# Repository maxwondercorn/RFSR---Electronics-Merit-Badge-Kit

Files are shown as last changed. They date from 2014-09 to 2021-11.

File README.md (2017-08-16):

Electronics Merit Badge Kit
==================================

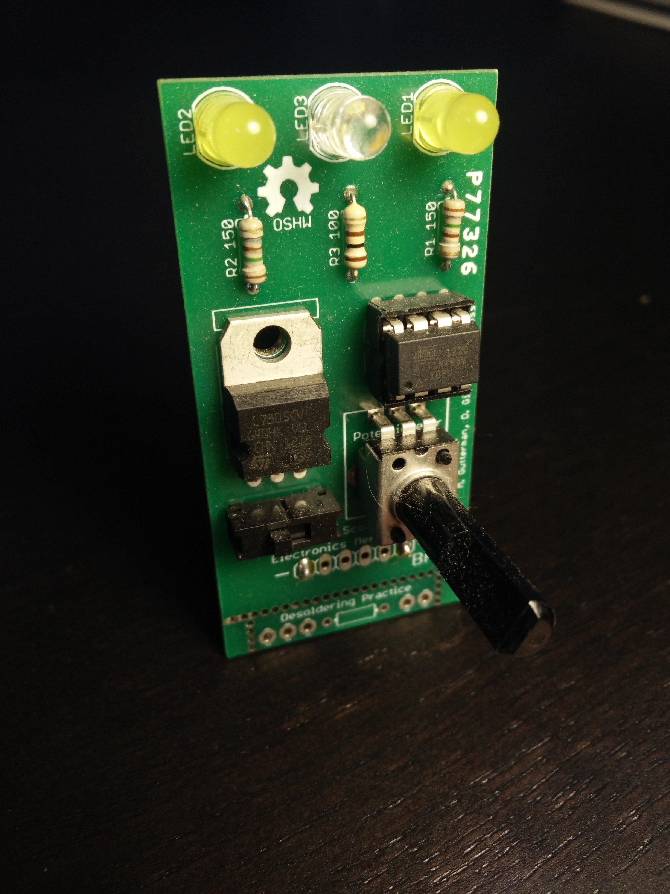
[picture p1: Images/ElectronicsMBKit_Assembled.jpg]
Electronics MB Kit Assembled


Small ATtiny (Arduino IDE Compatible) microcontroller based kit used to teach Electronics Merit Badge at Resica Falls Scout Reservation.  Once assembled and functional, the kit allows selection of various LED display modes (Flickering Candle, Nightlight, Flashlight, Etc.) by rotating the on-board potentiometer.  Kit design is intended to meet all relevant badge requirements and expose scouts to a variety of component types at the lowest cost possible.

Repository Contents
-------------------

* **/Hardware** - Eagle Schematic / PCB Layouts & Bill Of Materials
    - PCB silkscreen periodically updated to match summer camp staff members currently teaching Electronics Merit Badge at Resica Falls Scout Reservation.
    - Bill Of Materials includes vendors / part numbers from the last production run.
* **/Software** - Demo Arduino sketch for the kit.  Code is intended to be easy to understand for beginners.
* **/Images** - Images of the kit, both assembled and in parts.

Firmware Programming
-------------------

As of the 2017 summer camp season, kit firmware is programmed using the following tools:

#### Hardware
An [Arduino Uno](https://store.arduino.cc/usa/arduino-uno-rev3) and an [AVR Programmer Shield](http://www.electrodragon.com/w/AVR_Programmer_Arduino_Shield) with ZIF socket.

Image of programming rig: [/Images/ElectronicsMBProgrammingRig.jpg](https://raw.githubusercontent.com/crossfireprod/RFSR---Electronics-Merit-Badge-Kit/master/Images/ElectronicsMBProgrammingRig.jpg)

#### Software
The Arduino Uno is used as an in system programmer (ISP) through use of the [ArduinoISP](https://github.com/arduino/ArduinoISP) sketch packaged with [Arduino 1.8.3](https://www.arduino.cc/en/main/software) to program the ATtiny 45/85 targets.  ATtiny core files available from [David Mellis' GitHub Repository](https://github.com/damellis/attiny), using [full instructions published by high-low tech](http://highlowtech.org/?p=1695) allow the ATtiny AVR microcontrollers used in the kits to be programmed directly from the Arduino IDE.

License
-------------------

All contents of this repository are released under [Creative Commons Share-alike 4.0](http://creativecommons.org/licenses/by-sa/4.0/).



Kit Design By: [*ZachCross.com*](https://ZachCross.com)

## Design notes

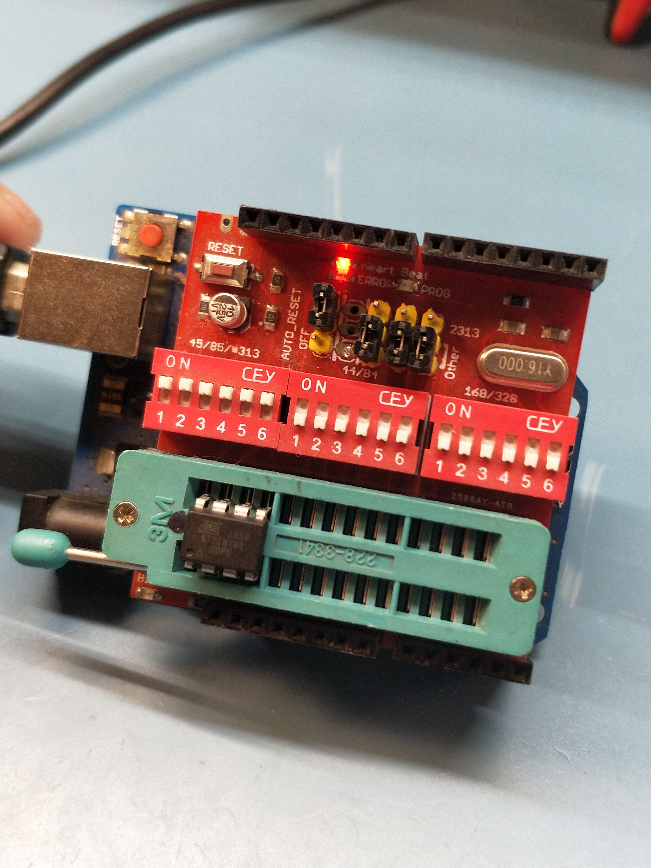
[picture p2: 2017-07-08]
Images/ElectronicsMBProgrammingRig.jpg

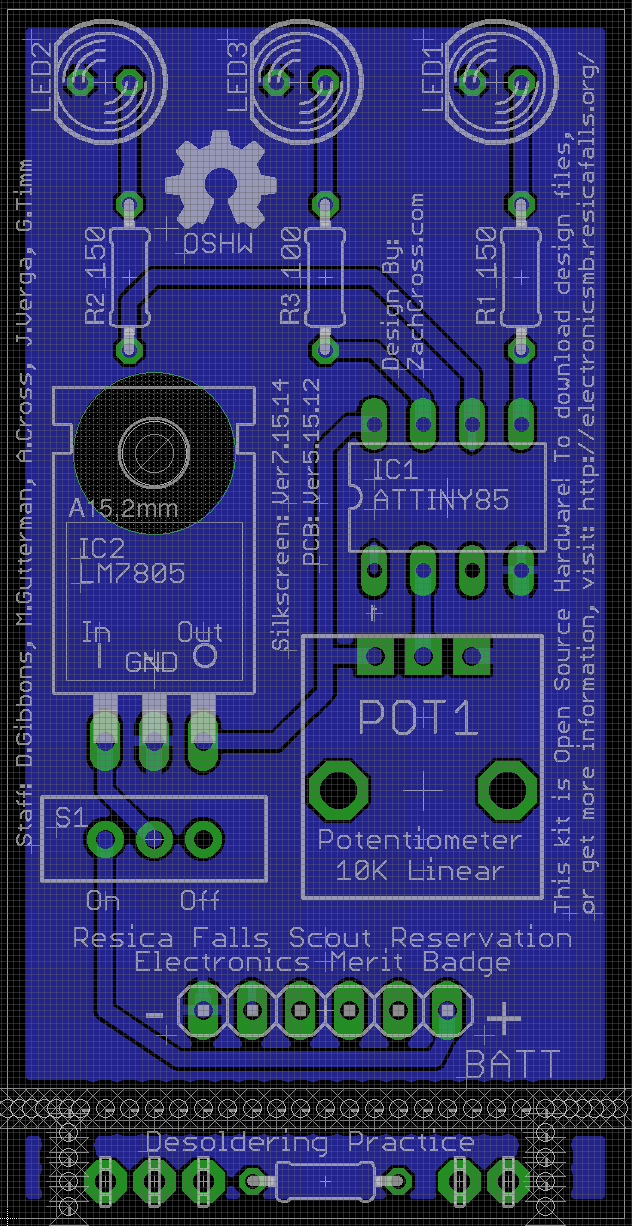
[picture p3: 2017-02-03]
Images/ElectronicsMBKit_PCBLayout.png

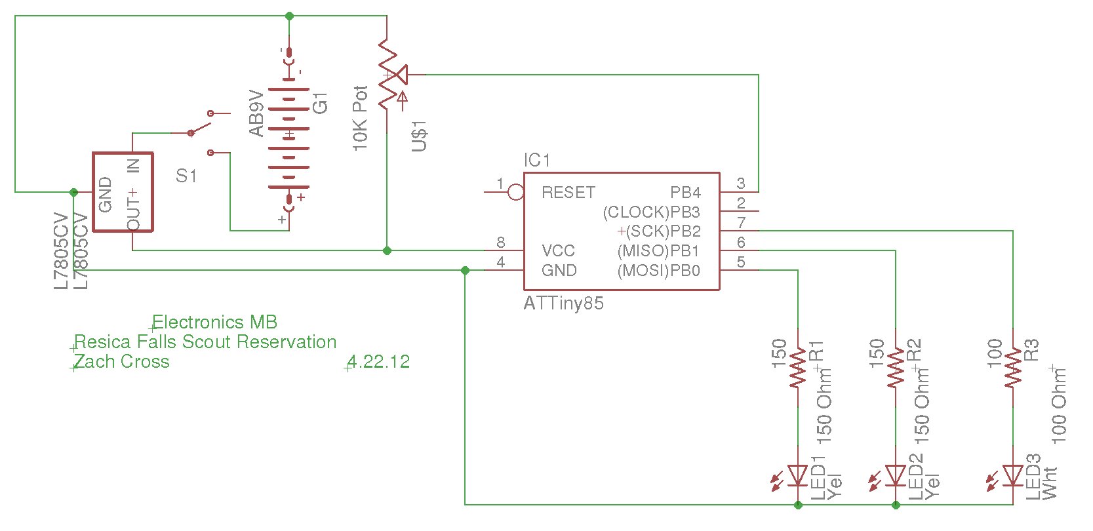
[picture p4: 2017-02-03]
Images/ElectronicsMBKit_Schematic.png

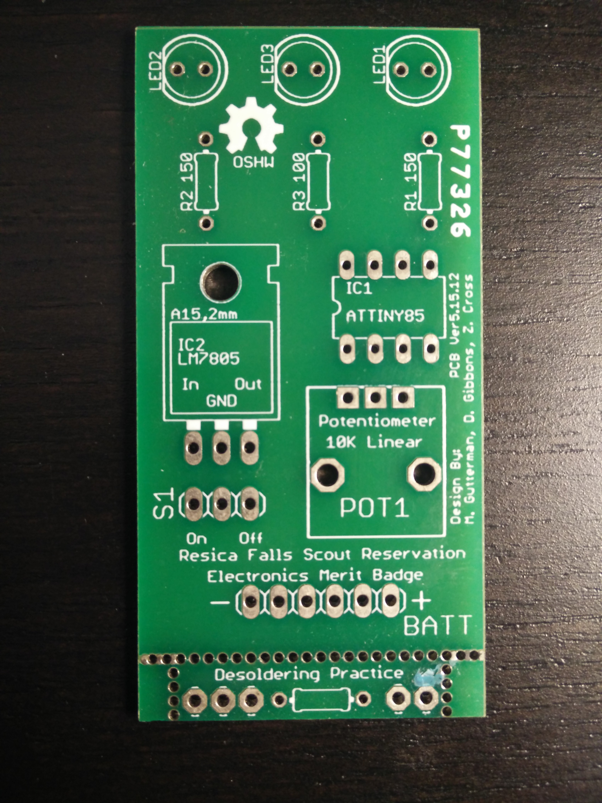
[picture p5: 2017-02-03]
Images/ElectronicsMBKit_BarePCB.jpg

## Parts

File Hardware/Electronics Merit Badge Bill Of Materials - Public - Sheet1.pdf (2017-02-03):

Item | Refrence Designator | Part No. | Vendor
5mm Yellow LED | LED1, LED2 | A-1555 | http://www.taydaelectronics.com/led-5mm-yellow.html
5mm White LED | LED3 | A-408 | http://www.taydaelectronics.com/led-5mm-white-water-clear-ultra-bright.html
ATTiny45 | IC1 | ATtiny45-20PU | http://www.mouser.com/ProductDetail/Atmel/ATtiny45-20PU/?qs=sGAEpiMZZMvqv2n3s2xjsVIKSdqlAUq6Klh%252bsqgDu4U%3d
10K Potentiometer | POT1 | EVU-F2AF30B14 | http://search.digikey.com/scripts/DkSearch/dksus.dll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
9V Battery Holder | BATT | 12BH611-GR | http://www.mouser.com/ProductDetail/Eagle-Plastic-Devices/12BH611-GR/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
150 Ohm Resistor | R1, R2 | A-2059 | http://www.taydaelectronics.com/10-x-resistor-150-ohm-1-4w-5-carbon-film-pkg-of-10.html
100 Ohm Resistor | R3 | A-2051 | http://www.taydaelectronics.com/10-x-resistor-100-ohm-1-4w-5-carbon-film-pkg-of-10.html
SPDT Slide Switch | S1 | EG1903-ND | http://www.digikey.com/product-detail/en/EG1218/EG1903-ND/101726
5V Linear Voltage Regulator | IC2 | L7805CV | http://www.taydaelectronics.com/lm7805-l7805-7805-voltage-regulator-ic-5v-1-5a.html
8 Pin DIP Socket | IC1 Socket | A-001 | http://www.taydaelectronics.com/8-pin-dip-ic-socket-adaptor-solder-type.html
PCB | N/A | | Advanced Circuits (http://www.4pcb.com/)
9V Battery | N/A | DU9V | http://www.bhphotovideo.com/c/product/182697-REG/Duracell_MN1604_9V_Alkaline_Battery_Coppertop.html

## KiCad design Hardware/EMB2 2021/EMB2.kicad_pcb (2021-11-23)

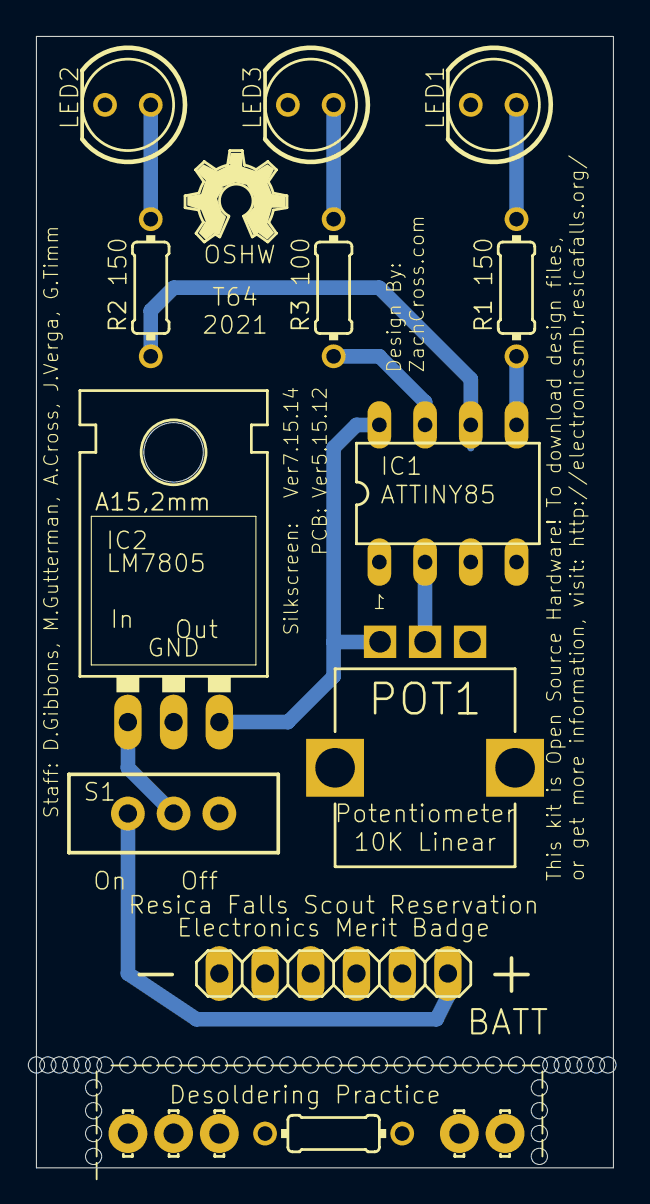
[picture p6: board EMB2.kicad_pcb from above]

Board: 2 copper layers, 32.1 x 62.9 mm, 58 parts (0 on the bottom side), 4 nets.

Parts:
10K_LIN_POT: 10K Lin Pot; PTV09A-4025F-B103
7805: 78XXL
@HOLE0, @HOLE1, @HOLE2, @HOLE3, @HOLE4, @HOLE5, @HOLE6, @HOLE7, @HOLE8, @HOLE9, @HOLE10, @HOLE11, @HOLE12, @HOLE13, @HOLE14, @HOLE15, @HOLE16, @HOLE17, @HOLE18, @HOLE19, @HOLE20, @HOLE21, @HOLE22, @HOLE23, @HOLE24, @HOLE25, @HOLE26, @HOLE27, @HOLE28, @HOLE29, @HOLE30, @HOLE31, @HOLE32, @HOLE33, @HOLE34, @HOLE35, @HOLE36, @HOLE37, @HOLE38, @HOLE39: (no value)
E$2: 1X06
E$3: OSHW_FILLX200_NOTEXT
E$5, E$6, E$7, E$8, E$9: LSP11
IC1: ATTiny85; DIL08
L1, L2: Yel; LED5MM
L3: Wht; LED5MM
PRACTICE: 0204_7
R1, R2: 150; 0204_7
R3: 100; 0204_7
S1: SWITCH-SPSTPTH; SWITCH-SPDT

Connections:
GND: 7805.GND, E$2.1, L1.K, L2.K, L3.K
unnamed: IC1.5, R1.1
unnamed: IC1.6, R2.1
unnamed: IC1.7, R3.1

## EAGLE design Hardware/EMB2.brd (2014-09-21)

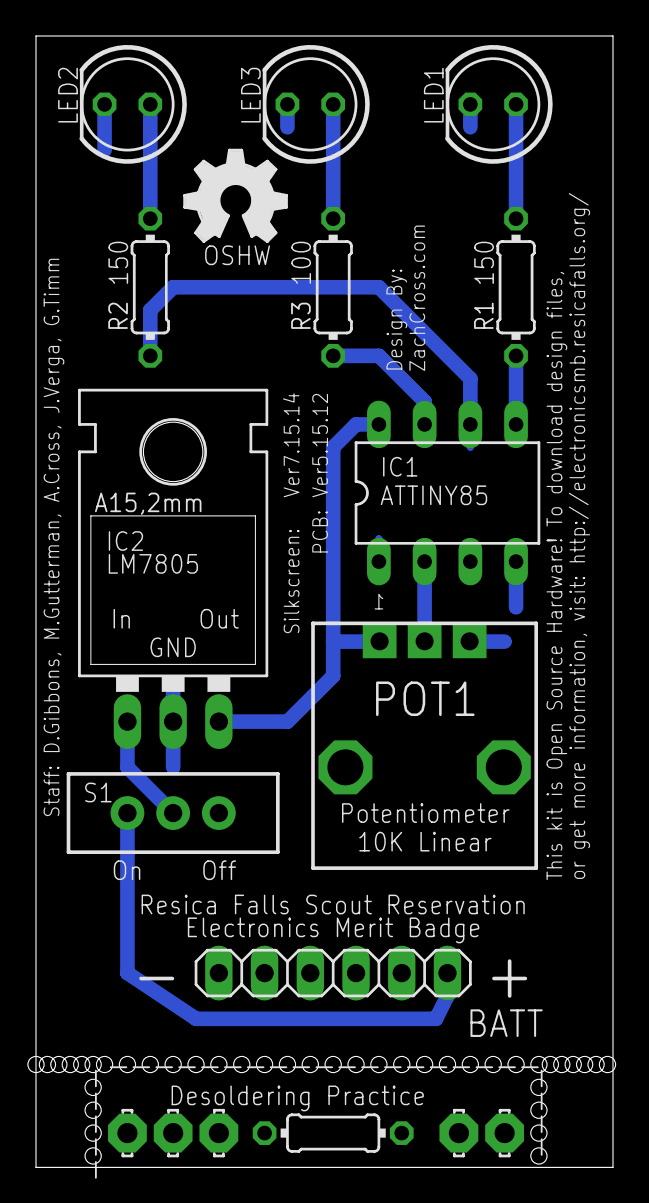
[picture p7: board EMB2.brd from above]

Board: 2 copper layers, 32.1 x 62.9 mm, 18 parts (0 on the bottom side), 10 nets.

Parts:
10K_LIN_POT: 10K Lin Pot; ALPS_POT
7805: 78XXL
E$2: 1X06
E$3: OSHW_FILLX200_NOTEXT
E$5, E$6, E$7, E$8, E$9: LSP11
IC1: ATTiny85; DIL08
L1, L2: Yel; LED5MM
L3: Wht; LED5MM
PRACTICE: 0204/7
R1, R2, R3: 0204/7
S1: SWITCH-SPDT

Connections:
GND: 7805.GND, E$2.1, IC1.4, L1.K, L2.K, L3.K
unnamed: 7805.IN, S1.2
unnamed: L1.A, R1.2
unnamed: L2.A, R2.2
unnamed: L3.A, R3.2
S$3: IC1.5, R1.1
S$4: 7805.OUT, IC1.8
S$5: E$2.6, S1.3
S$7: IC1.6, R2.1
S$8: IC1.7, R3.1

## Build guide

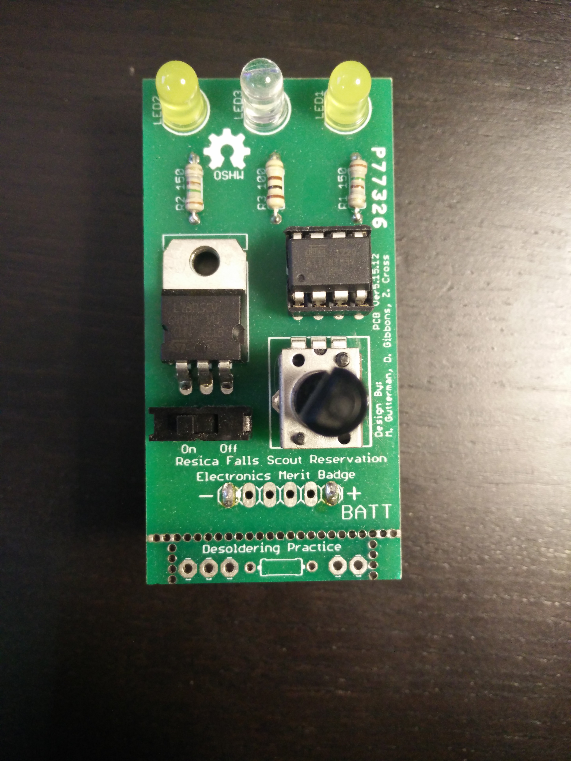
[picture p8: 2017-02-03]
Images/ElectronicsMBKit_AssembledFrontProfile.jpg

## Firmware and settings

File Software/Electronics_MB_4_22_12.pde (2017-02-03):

/**********************************
 * Resica Falls Scout Reservation *
 * Electronics Merit Badge Kit    *
 *                                *
 * - Electronic Candle            *
 * - Tent Light                   *
 * - Flash Light                  *
 *                                *
 * CodeVer: 7-14-14               *
 *                                *
 *********************************/

// Set a constant name for each pin.
int const LED1 = 0;    // Yellow LED 1
int const LED2 = 1;    // Yellow LED 2
int const LED3 = 2;    // White LED
int const potPin = 3;  // Pin to get reading from potentiometer.


void setup() { // Everyting in here will be run only once each time the microcontroller is powered on.

  pinMode(LED1, OUTPUT);   // Set pin the LED1 is connected to as an output.
  pinMode(LED2, OUTPUT);   // Set pin the LED2 is connected to as an output.
  pinMode(LED3, OUTPUT);   // Set pin the LED3 is connected to as an output.

  pinMode(potPin, INPUT);  // Set pin that the potentiometer is connected to as an input.

  // Brief initialization sequence.  Flash each LED to check for assembly errors.
  digitalWrite(LED1, HIGH);
  delay(500);
  digitalWrite(LED1, LOW);
  delay(500);
  digitalWrite(LED2, HIGH);
  delay(500);
  digitalWrite(LED2, LOW);
  delay(500);
  digitalWrite(LED3, HIGH);
  delay(500);
  digitalWrite(LED3, LOW);
  delay(500);
  digitalWrite(LED1, HIGH);
  digitalWrite(LED2, HIGH);
  digitalWrite(LED3, HIGH);
  delay(1000);
  digitalWrite(LED1, LOW);
  digitalWrite(LED2, LOW);
  digitalWrite(LED3, LOW);
} // END Setup


void loop() { // Everything in here will be run over and over once setup is complete.

 int potValue = (analogRead(potPin) / 4);      // Get value from potentiometer to determine what to do.

 if (potValue < 5) {                           // If potentiometer is turned all the way down:
   digitalWrite(LED3, LOW);                    // Turn off White LED.
   flickerLED();                               // Flicker the Yellow LEDs

 } else if (potValue > 5 && potValue < 250) {  // If potentiometer is somewhere in the middle:
     digitalWrite(LED3, LOW);                  // Turn off White LED.
     analogWrite(LED1, potValue);              // Set Yellow LED1 to brightness value read from potentiometer.
     analogWrite(LED2, potValue);              // Set Yellow LED2 to brightness value read from potentiometer.

 } else if (potValue > 250) {                  // If potentiometer is turned all the way up:
     digitalWrite(LED3, HIGH);                 // Turn on the white LED.
     digitalWrite(LED1, LOW);                  // Turn off Yellow LED1
     digitalWrite(LED2, LOW);                  // Turn off Yellow LED2
 }

} // END Loop


void flickerLED() { // Everytihng in here will be run once each time flickerLED() is called.
  analogWrite(LED1, random(120)+135);  // Set Yellow LED1 to a random brightness.
  analogWrite(LED2, random(120)+135);  // Set Yellow LED2 to a random brightness.
  delay(random(50));                   // Wait a random amount of time before returning to the loop and doing it again.

} // END flickerLED

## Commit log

2017-02-03 Added supporting documentation.
    [Board_5.15.12.brd, Board_7.15.14.brd, Schematic_4.22.12.sch]
2021-11-23 feat: Converted to KiCad
    [EMB2.kicad_pcb, EMB2.sch]
2021-11-23 chore: Eagle project imported
    Rnamed so it could be imported into KiCad
    [EMB2.brd, EMB2.sch]
2021-11-23 Create gerber file
    [EMB2-B_Mask.gbr, EMB2-B_Paste.gbr, EMB2-B_SilkS.gbr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]
2021-11-23 Added missing keepout zone
    [EMB2-B_Mask.gbr, EMB2-B_Paste.gbr, EMB2-B_SilkS.gbr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]
